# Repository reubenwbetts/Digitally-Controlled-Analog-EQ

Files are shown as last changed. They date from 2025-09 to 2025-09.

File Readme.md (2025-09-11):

 **Digitally-Controlled Analog EQ for Bus Processing in Dolby Atmos**

This was my Final Year Project, which demonstrates a unique and natural way to integrate analog hardware into multi-channel workflows through the use of digital control. It also includes an algorithim for manipulating effects processing in the spatial domain with three potentiometers, simplifying the UI massively from other products on the market.

**System Overview**

Per-channel, the system comprises of an analog EQ, whose paramters are contolled from an array of digipots (digital potentiometers). The specific digipot chosen was the AD5290 as it allows for bi-polar signals to be passed through, and also has very low distortion (0.006% typical) which removes the need for any signal conditioning (biasing/gain-staging). These present a massive advantage over using either VCA/VCF chips or a transistor as a crude voltage controlled resistor, as they can be effectively dropped in as a replacement for a physical potentioemter, excluding the digital control circuitry. 

The microcontroller reads a set of physical potentiometers (low shelf gain, low shelf frequency etc..) and then proceses and passes these values to the digipots over an SPI bus, allowing the microcontroller to translate a single input, such as input gain to 12 channels simultaneously. The AD5290's are able to be configured in daisy chain mode, which means all of them can be controlled off of a single, three-wrie SPI bus (CS, SCK, MOSI). The only requirement here is that all digipots must be updated simultaneusly, which leads to a large amount of identical data to be passed thorugh every time a single parameter is changed. 

PCB layouts, Spice Sims, Code and a write-up for each section are availabe in their respective folders.

<p align=center> 

<p align=center> Early version of the system, without the mounting board.

<p align=center> 

<p align=center> Later version, with the mounting board, a pair of EQ channels and 12 digipots.

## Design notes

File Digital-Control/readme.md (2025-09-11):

**Digital Control**

Whilst the overall system is relatively simple, the digital control circuitry can become quite complex due to possible zipper nosie from performing discrete parameter changes. As the digipots are 8-bit, even small parameter changes can lead to sharp edges on the audio signal, which if large enough, could create audible clicking sounds to be mixed into the audio signal. To avoid this, a zero-cross detection ciruit was created to ensure parameter changes only take place when the signal passing through a digipot is at a zero-crossing.

This was done through a pair of comparators, which would change to a high state when the signal was in the range of +/-50Mv, and their outputs were ANDed to create a pulse at the singals zero-crossing. This was then ANDed with the CS line, which meant only when CS was high, and a zero crossing had occured, that the AD5290's CS input would become high. 

The AD5290's required a low CS input to be written to their input buffer, and a high state to move the wiper position to the position stored in the buffer. This meant that the microcontroller could set the CS line to low whilst each digipot was written to, and once the data was transferred, a zero-crossing pulse at each digipots input would update them all indepently of the MCU, exactly when a zero-crossing took place.

A final consideration was that due to propogation delay from the ZCD circuit and the two logic gates (around 70ns), the CS update may end up taking place outside of the zero-crossing. To fix this, a bessel filter was also implemented to delay the audio signal (a matlab script was created to calculate the values), re-syncing the two waveforms. However, in practise the propogation delay was insignificant enough to warrant using it.

<p align=center> 

<p align=center> Assembled digipot board, with 4 digipots + ZCD circuits.

<p align=center> 

<p align=center> ZCD circuit being fed a 20kHz sine wave (output was inverted due to not having the correct logic gates on hand) 

<p align=center> 

<p align=center> Signal flow diagram of the ZCD system

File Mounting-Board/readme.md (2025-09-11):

This project was started using EasyEDA, which did not include gerber export. After the project was submitted PCB design was moved to KiCad, which allowed the mounting board PCB to be uploaded as a set of gerber files. 

All this board does is connect different though-hole sockets together (and a simple 5v generator with a regulator), so a schematic was not needed. 

<p align=center> 

<p align=center> Mounting board with Teensy + a set of digipot boards mounted.

<p align=center> 

<p align=center> Mounting board with EQ, Teeensy and digipot boards mounted.

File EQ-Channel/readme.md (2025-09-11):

**EQ Channel PCB**

A set of schematics, SPICE sims and PCBs for an individual EQ Channel

Each channel consists of:
- De-balancing input
- Gain Stage
- Passive RC HPF
- 4 EQ bands, a low-shelf, two mid-bells and a high-shelf
- Balanced output

Each stage starts with a buffered output, which is passed to the ZCD/Digipot board for generating the CS pulse for the assosciated digipots. Then, the signal is (supposed to be) passed to a bessel filter before being processed to further synchronise the audio signal with the ZCD circuitry, although this is not actually necessary. 

The EQ stages are based on the wein-bridge topology which function as so:
- The signals phase is inverted, then inverted again.
- A wein-bridge network (effectively an RC bandpass) is fed either the in-phase version of the signal, or the inverted version, with the amount determined by the 'gain' potentiometer.
- The output of the wein-bridge is summed with the input signal, creating either a boost or a cut, depending on the positon of the gain-potentiometer.

This is the exact method for the bell stages, however the shelves are created by omitting one half of the wein-bridge (resulting in either an LPF or a HPF). 

<p align=center>

<p align=center> A fully assembled EQ board.

_This PCB design could definetely be improved, the return currents for the power rails are blocked by the power rails themselves, forcing the return currents to go through a very narrow spot._

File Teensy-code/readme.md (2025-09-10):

**Example code for a single channel of EQ using four digipot boards (12 digipots) with a Teensy 4.1**

In this example, the Teensy reads in a set of 8 inputs, and distributes them to 12 digipots (to form a single channel of EQ).

- Input 1 (High Shelf Gain) - Digipot 12 
- Input 2 (High Shelf Frequency) - Digipot 11 + 10
- Input 3 (High Mid Bell Gain) - Digipot 9 
- Input 4 (High Mid Bell Frequency) - Digipot 8 + 7
- Input 5 (Low Mid Bell Gain) - Digipot 6 
- Input 6 (Low Mid Bell Frequency) - Digipot 5 + 4
- Input 7 (Low Shelf Gain) - Digipot 3 
- Input 8 (Low Shelf Frequency) - Digipot 2 + 1

As the digipots are configured in daisy chain mode, the data on the SPI bus is pushed through the system. If N = TXBuffer's length in bytes (12 in this case), and the digipots are numbered based on their position on the physical bus (digipot 1 is the closest to the MCU/first in the chain) then by the time the transfer has finished, the first byte sent will end up in digipot N, the second byte N-1, then N-2 etc...

The code is structured as so:

- Read in pots to an Array
- Filter out any noise with a pair of fixed-point IIR's 
- Distribute the filtered signal to the SPI TXBuffer.
- Compare this TXBuffer to the previous buffer created and if difffernt, update the digipots.

**THIS CODE IS SLOW, ANALOGREAD ADDS A MASSIVE OVERHEAD, BUT IT WORKS AS A PROOF-OF-CONCEPT**

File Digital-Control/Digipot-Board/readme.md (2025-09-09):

Unfortunately, the EasyEDA project for the digipot boards corrupted, and so no schematic for the ZCD is available. However, it is identical to the SPICE sim so that can be used instead.

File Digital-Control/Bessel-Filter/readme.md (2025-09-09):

**A set of Matlab scripts for calculating Bessel filter component values**

Included is a set of matlab scripts, which can be used in conjuction with the SPICE simulation to verfy the calculations.

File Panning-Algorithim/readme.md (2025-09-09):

This requires the RNBO extension for maxMSP. It is configured to be 7.1.4 currently, so has 12 channels in, 12 out. In the bottom right of the RNBO patch, the GUI can be found: 



**Algorithim Explanation**

This algorithim allows for a set of input parameters (EQ in this case) to be distributed across 12 channels, and 'spataily-weight' them based on three extra parameters:

- latitude
- longitude
- spatial-q

The EQ parameters will be reffered to as 'processor parameters', and the spatial controls 'spatial parameters'.

It works as so:

- Each channel is positioned on a sphere and assigned a set of co-ordinates, latitude and longitude. These follow the offical Dolby Atmos specification, but could be re-arranged however the user sees fit. Extra channels can also be added/removed, allowing it to be configured as a 9.1.6, 5.1.2 system etc. 

- The user inputs a set of processor parameters, and a set of spatial parameters. 

- The processor parameters are stored, and based on the spatial parameters a scaling value is created for each channel, which is determined by the channel's distance to the latitude and longitude values (user position), and then scaled by the spatial-q value. 

- The processor parameters are then scaled per-channel by the scaling values generated earlier, meaning the closer to the user postion each channel is, the more pronounce the EQ curve becomes, and as you move away from the user positon, the EQ curve becomes flat. 

- Spatial-Q simply changes the distance at which the EQ curve becomes flat, allowing for the EQ curve to become more/less focused at the area around the user position.

This allows the user to perform spatial-tone shaping, by altering the frequnecy repsonse of certain areas in the mix, without having to tweak values per-channel. Whilst not tehcnically an object-audio based sytem, it allows the EQ curve to be used like an object, and be postioned (which to me, is a much much more natural way of handling FX processing in Atmos).

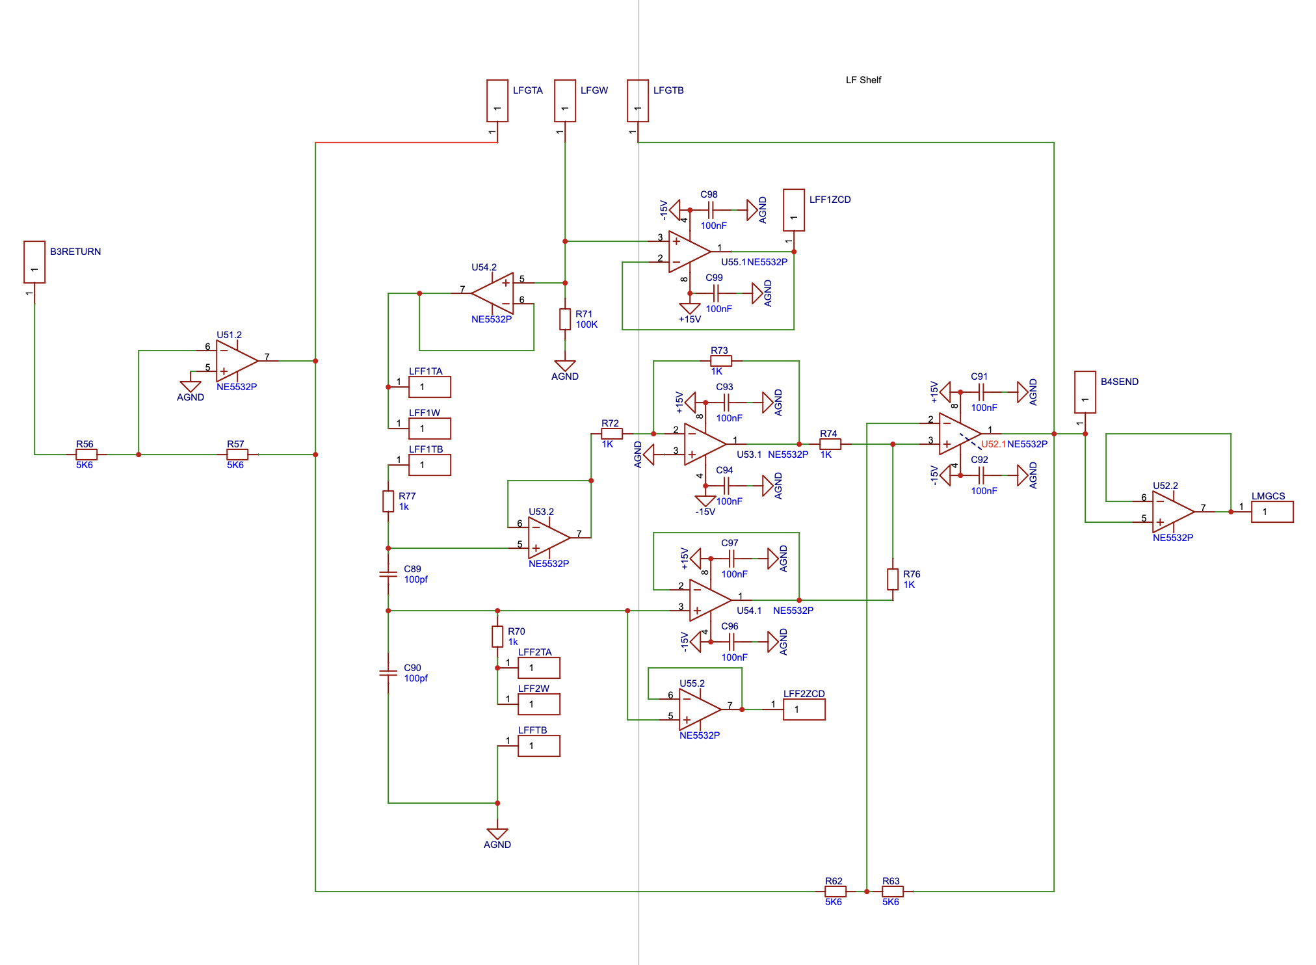
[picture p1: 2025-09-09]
EQ-Channel/Schematics/Low Shelf.png

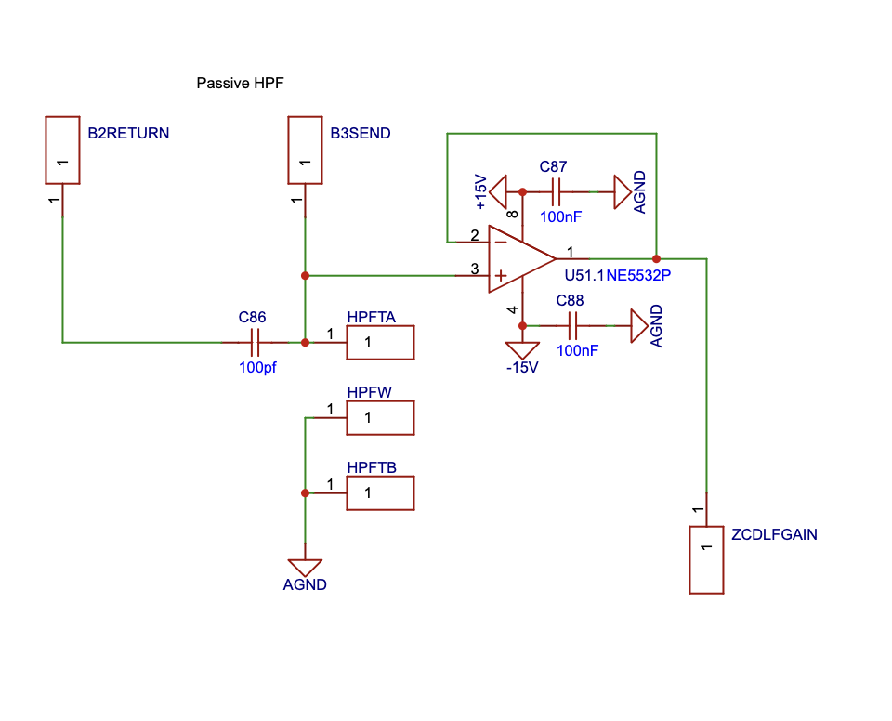
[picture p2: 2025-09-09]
EQ-Channel/Schematics/HPF.png

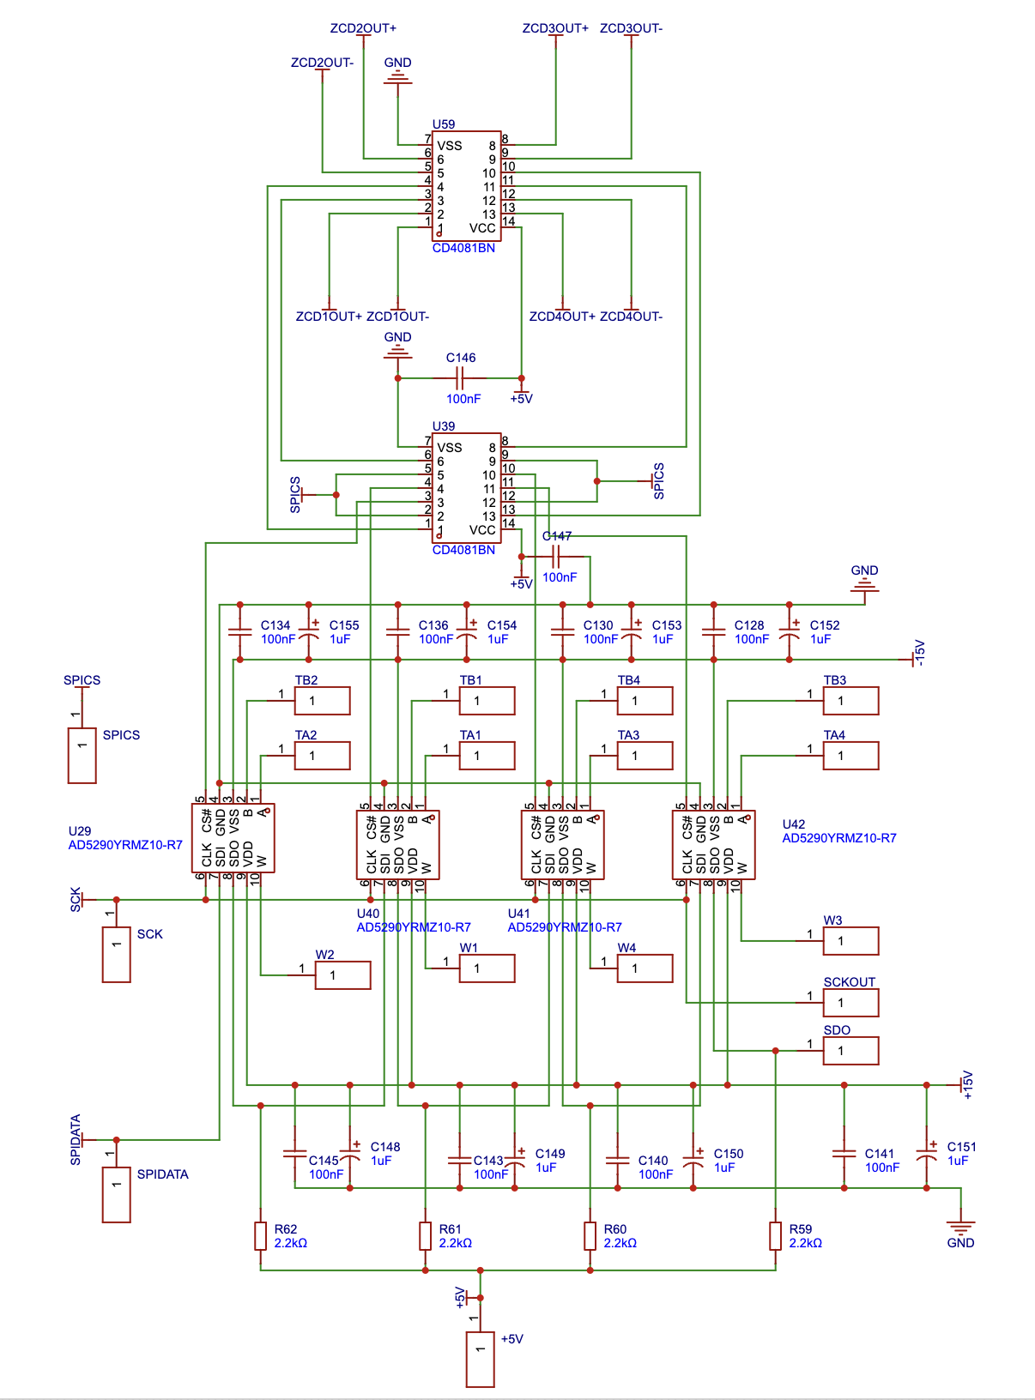
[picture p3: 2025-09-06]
Digital-Control/Digipot-Board/Schematics/CS-Line-Interface.png

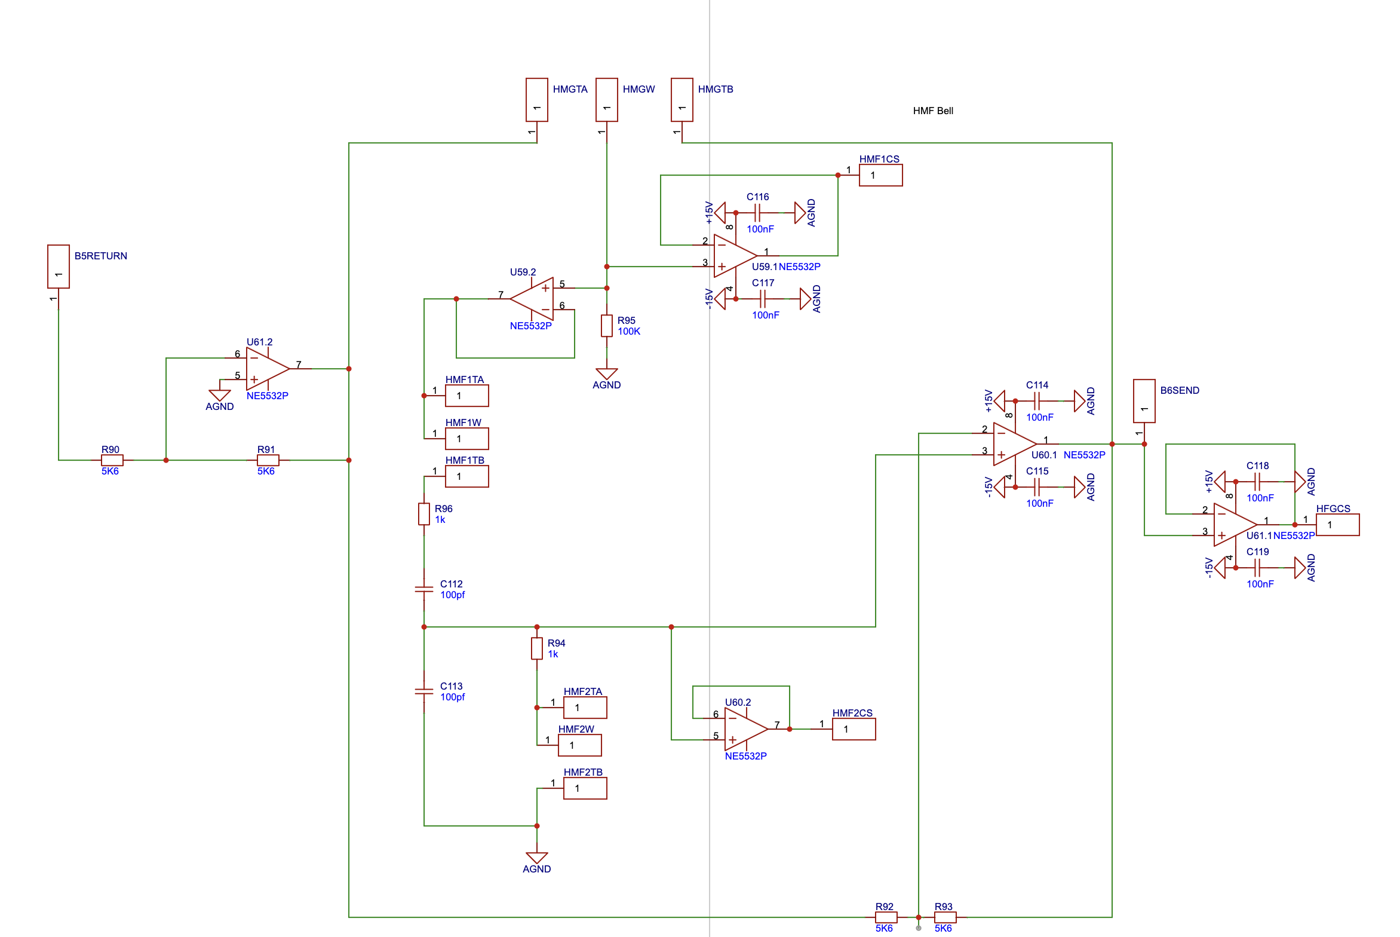
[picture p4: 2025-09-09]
EQ-Channel/Schematics/High Mid Bell.png

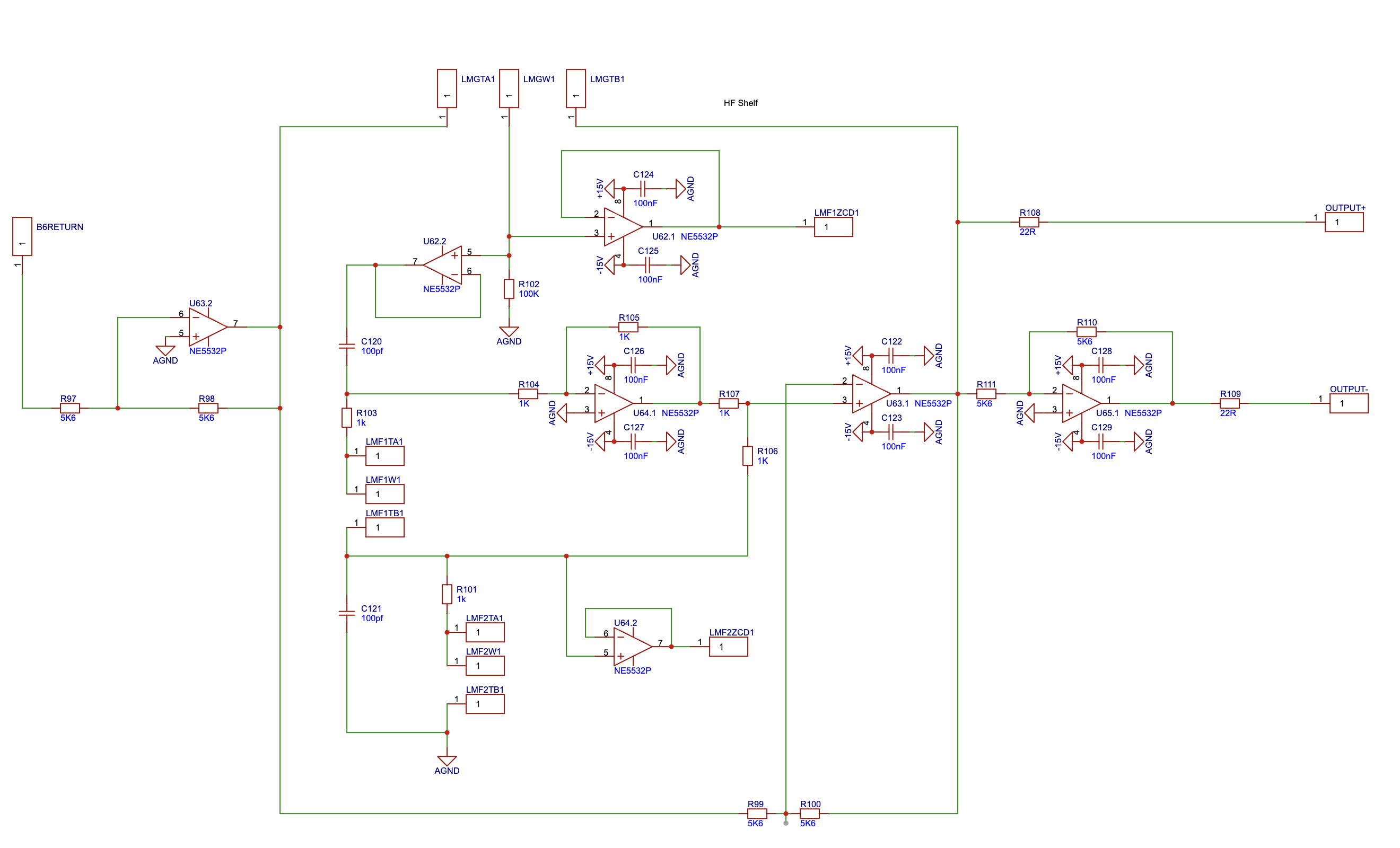
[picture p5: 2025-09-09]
EQ-Channel/Schematics/High Shelf + Output.png

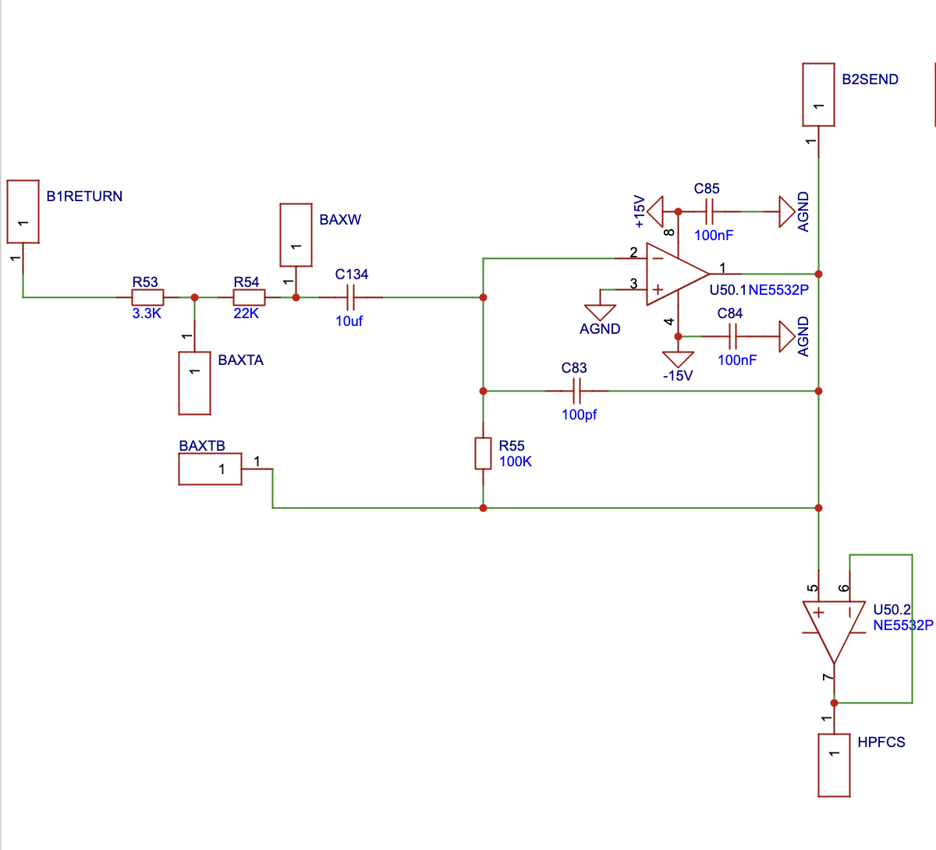
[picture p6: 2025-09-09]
EQ-Channel/Schematics/Active Gain.png

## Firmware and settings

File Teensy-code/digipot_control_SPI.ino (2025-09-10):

#include <SPI.h>
#include "one_pole_iir.h"

uint8_t input_pot_values[8] = {127,127,127,127,127,127,127,127   };
uint8_t digipot_values_past[12] = {   };
uint8_t digipot_values[12] = {   };
uint8_t input_pots[8] = {16,17,18,19,20,21,22,23};

one_pole_iir potfilter[16];
uint8_t filter_input;

/* 
using Q8.8, so 255 = overdamped, 0 = nodamping
filter is in fixed-point, and wanted to keep filters super duper light so it uses 16 bit resolution inside the filter. this causes a DC sag at high damping values, so don't put them tooo high (>150).
  */
uint16_t input_pot_damp_val = 150; 

EventResponder spiDone;
volatile bool spiBusy = false;

void spiFinished(EventResponderRef event) {
  spiBusy = false;  
  digitalWriteFast(SS, HIGH);
}

void setup() {
  Serial.begin(9600);
  analogReadResolution(8);
  // set the slaveSelectPin as an output:
  pinMode(SS, OUTPUT);
  digitalWriteFast(SS, HIGH);
  // initialize SPI:
  SPI.begin();
  SPI.beginTransaction(SPISettings(2000000, MSBFIRST, SPI_MODE0));
  spiDone.attachImmediate(spiFinished);
  // assign all pot pins as inputs
  for (int i = 0; i < 8; i++){
    pinMode(input_pots[i], INPUT);
  }
}

void loop() {

  uint8_t counter = 0;
  bool pot_changed = 0;

  for (int i = 0; i < 8; i++){

    /* read pots - analogRead is the bottleneck 
    in this code, need to replace it */
    

    input_pot_values[i] = analogRead(input_pots[i]); 
    
    // filter input pots with two single pole IIR's, should do a second order but didn't have time.
    input_pot_values[i] = potfilter[i].filter_method(input_pot_values[i],input_pot_damp_val);  
    input_pot_values[i] = potfilter[i+8].filter_method(input_pot_values[i],input_pot_damp_val);
    
    /* distribute inputs to the correct positons 
      in digipot array (1,2,2,3,4,4 etc..)   */
    digipot_values[counter] = input_pot_values[i];
    counter++;
    if (i % 2 != 0){
      digipot_values[counter] = digipot_values[counter-1];
      counter++;
    } 

  }

  Serial.print("baseline:");
  Serial.println(0);
  Serial.print("filtered:");
  Serial.println(digipot_values[11]);
  Serial.print("topline:");
  Serial.println(255);
  // check for any changed values and update past values to current
  for (int i = 0; i<12; i++){
    if (digipot_values_past[i] != digipot_values[i])
    {pot_changed = 1;}
    digipot_values_past[i] = digipot_values[i];
  }

  // transmit over DMA if any values have changed 
  if (!spiBusy && pot_changed == 1){
    digitalWriteFast(SS, LOW);
    spiBusy = true;
    SPI.transfer(digipot_values, 0, 12, spiDone);
  }

}
